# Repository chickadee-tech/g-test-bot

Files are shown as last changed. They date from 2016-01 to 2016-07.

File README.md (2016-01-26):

# Chickadee Tech Acro Polystack Mod #
This is the bottom of the test jig for Polystack **control** and **mod** boards.

## Documentation ##
See the [wiki](https://github.com/chickadee-tech/g-test-bot/wiki) for documentation.

## Polystack ##
This board is part of the Polystack platform for modular microcontrol systems. More information on the platform can be found at [polystack.org](http://polystack.org).

## Support ##
If you need support with a board you own or have development questions please email support@chickadee.tech or check [chickadee.tech/support](https://chickadee.tech/support) for other ways to get support.

## Contributing ##
Please note that this project is released with a [Contributor Code of Conduct](CODE_OF_CONDUCT.md). By participating in this project you agree to abide by its terms.

### Setup ###
Components and footprints for PCB parts are not included in this repository. Instead, checkout the [chickadee-tech/kicad-libs](https://github.com/chickadee-tech/kicad-libs) repository in the same directory that this repository is checked out in. All part definitions should be relative so that they will load correctly.

### Pull requests ###
For fixes please submit a pull request to the original repository. After the pull request is merged, check the [Chickadee Tech Active Contributor Discount (ACD)](https://chickadee.tech/active-contributor) to see if you are eligible for a discount code to use on your next purchase.

### Derivatives ###
If developing your own version of the test jig bottom board please remove all Chickadee Tech trademarks and follow the [CC-BY license](pcb/LICENSE) for the PCB and the MIT license for the code. While not required, please consider open sourcing your modifications so others can learn from your improvements. If you do email support@chickadee.tech and we may choose to add your project to the ACD.

You may also license the Polystack logo for free by emailing support@chickadee.tech. We'll ask for your gerbers to ensure the design complies with specifications laid out [here](https://github.com/chickadee-tech/polystack/wiki) and provide written permission to use the trademark after compliance has been demonstrated.

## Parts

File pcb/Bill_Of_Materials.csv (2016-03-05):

part name | symbol | size (imp) | max current | unit price | units per build | units in stock | order total | Manufacturer ID | source url | datasheet | datasheet2
C 2.2uF | C1 | 603 |  | $0.05 | 1 | 92 | $0.05 | C0603C225K9PACTU | http://www.digikey.com/product-detail/en/C0603C225K9PACTU/399-3362-1-ND/650351 |  |  |  | Total Base Cost | $51.09
C 1uF X7R | C2 | 603 |  | $0.03 | 1 | 20 | $0.03 | TMK107B7105KA-T | http://www.digikey.com/product-detail/en/TMK107B7105KA-T/587-2984-1-ND/2714177 | MF-CAP-0603-1uF | http://ds.yuden.co.jp/TYCOMPAS/ut/detail.do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 | price ranges 1.40 - 2.50
barrel jack smd | CON1 |  |  | $1.18 | 1 | 1 | $1.18 | PJ-102AH | http://www.digikey.com/product-search/en?keywords=PJ-102AH | N
red led | D1 |  |  | $0.19 | 1 | 71 | $0.19 | LTST-C190KRKT | http://www.digikey.com/product-detail/en/LTST-C190KRKT/160-1436-1-ND/386816 | MF-LED-0603-RED | http://optoelectronics.liteon.com/upload/download/DS-22-99-0151/S_110_LTST-C190KRKT.pdf
yellow led | D2 |  |  | $0.20 | 1 | 87 | $0.20 | LTST-C190KSKT | http://www.digikey.com/product-detail/en/LTST-C190KSKT/160-1437-1-ND/386818 | N | http://optoelectronics.liteon.com/upload/download/DS-22-99-0189/S_110_LTST-C190KSKT.pdf
green led | D3 |  |  | $0.19 | 1 | 83 | $0.19 | LTST-C190KGKT | http://www.digikey.com/product-detail/en/LTST-C190KGKT/160-1435-1-ND/386814 | Y | http://optoelectronics.liteon.com/upload/download/DS22-2000-074/S_110_LTST-C190KGKT.pdf
1x6 Female 5mm Tin | P1 |  |  | $1.20 | 1 | 1 | $1.20 | CES-106-01-T-S | http://www.digikey.com/product-detail/en/CES-106-01-T-S/SAM1087-06-ND/1104168 | N | http://suddendocs.samtec.com/prints/ces-dmkt.pdf
2x25 Female 5mm Tin | P2, P4 |  |  | $4.54 | 2 | 0 | $9.08 | CES-125-01-T-D | http://www.digikey.com/product-detail/en/CES-125-01-T-D/SAM1086-25-ND/1104099 | N | http://suddendocs.samtec.com/prints/ces-dmkt.pdf
1x4 Female 5mm Gold | P3 |  |  | $2.37 | 1 | 1 | $2.37 | CES-104-01-S-S | http://www.digikey.com/product-detail/en/CES-104-01-S-S/SAM1085-04-ND/1104070 | N | http://suddendocs.samtec.com/prints/ces-dmkt.pdf
side entry top 16pos 1mm | P5, P8 |  |  | $0.80 | 2 | 1 | $1.60 | SFW16R-2STE1LF | http://www.digikey.com/product-detail/en/SFW16R-2STE1LF/609-1908-1-ND/1003193 | N
20 pin receptacle (3.5mm) | P6 |  |  | $0.78 | 1 | 0 | $0.78 | DF40HC(3.5)-20DS-0.4V(51) |  | N | http://www.hirose.co.jp/cataloge_hp/ed_DF40_20140305.pdf
3.5mm pogopin | P7 |  |  | $1.41 | 1 | 0 | $1.41 | 0910-8-57-20-76-14-11-0 | http://www.digikey.com/product-detail/en/0910-8-57-20-76-14-11-0/ED1422CT-ND/5722687 | N | https://www.mill-max.com/assets/pdfs/metric/026M.pdf
80 pin receptacle (3.5mm) | PORT_OUT1 |  | 0.3A a pin | $2.42 | 1 | 1 | $2.42 | DF40HC(3.5)-80DS-0.4V(51) | http://www.digikey.com/product-detail/en/DF40HC(3.5)-80DS-0.4V(51)/H11997CT-ND/2880228 | N | http://www.hirose.co.jp/cataloge_hp/ed_DF40_20140305.pdf
n-channel mosfet | Q1 | TO-236-3, SC-59, SOT-23-3 | 220mA continuous | $0.09 | 1 | 59 | $0.09 | BSS138 | http://www.digikey.com/product-detail/en/BSS138/BSS138CT-ND/244294 | MF-DSC-SOT233-BSS138 | https://www.fairchildsemi.com/datasheets/BS/BSS138.pdf
R 1k | R1, R2, R3 | 603 |  | $0.01 | 3 | 993 | $0.03 | RC0603FR-071KL | http://www.digikey.com/product-detail/en/RC0603FR-071KL/311-1.00KHRCT-ND/729790 | MF-RES-0603-1K | http://www.yageo.com/NewPortal/yageodocoutput?fileName=/pdf/R-Chip/PYu-RC_Group_51_RoHS_L_3.pdf
R 0 | R4, R5 | 603 |  | $0.00 | 2 | 92 | $0.01 | RC0603JR-070RL | http://www.digikey.com/product-search/en?keywords=311-0.0grct-nd
dpdt | SW1 |  | 200mA | $1.35 | 1 | 0 | $1.35 | CL-SB-22B-02T | http://www.digikey.com/product-detail/en/CL-SB-22B-02T/563-1343-1-ND/3507867 | N | http://www.nidec-copal-electronics.com/e/catalog/switch/cl-sb.pdf
tactile switch top | SW2 |  |  | $0.24 | 1 | 3 | $0.24 | PTS645SK50SMTR92 LFS | http://www.digikey.com/product-search/en?keywords=ckn9087ct-nd | MF-SW-TACT-6MM
high side power switch | U1 | sot23-5 | 500mA | $0.65 | 1 | 0 | $0.65 | STMPS2151STR | http://www.digikey.com/product-detail/en/STMPS2151STR/497-6934-1-ND/1880312 | N | http://www.st.com/web/en/resource/technical/document/datasheet/CD00167470.pdf
3.3v regulator | U2 | SOT23-5 | 0.3A | $0.49 | 1 | 8 | $0.49 | TLV70233DBVR | http://www.digikey.com/product-detail/en/TLV70233DBVR/296-32415-1-ND/3505572 | MF-REG-SOT235-3.3V-300mA | http://www.ti.com/lit/ds/symlink/tlv702.pdf
4 x 1:2 | U3 | 16-VFQFN Exposed Pad |  | $0.63 | 1 | 1 | $0.63 | 74CBTLV3257BQ,115 | http://www.digikey.com/product-detail/en/nxp-semiconductors/74CBTLV3257BQ,115/568-5423-1-ND/2530901 | N | http://www.nxp.com/documents/data_sheet/74CBTLV3257.pdf
Generic Bottom Test Jig | Off board |  |  | $13.03 | 1 | 3 | $13.03 | CKD-G-TEST-BOT-V2 |  | N
STM32F3Discovery | STM32 F3 Discovery |  |  | $11.57 | 1 | 1 | $11.57 | STM32F3Discovery | http://www.digikey.com/product-search/en?keywords=stm32f3discovery | N | http://www.st.com/st-web-ui/static/active/en/resource/technical/document/user_manual/DM00063382.pdf
Nylon Hex Nut | Off board |  |  | $0.10 | 4 | 94 | $0.38 | 4688 | http://www.mouser.com/ProductDetail/Keystone-Electronics/4688/ | N | http://www.mouser.com/ds/2/215/688-744520.pdf
~1.25mm Spacer | Off Board |  |  | $0.08 | 4 | 8 | $0.34 | 908-050 |  | N
6" Premo Flex 16 pos FPC | Off board |  |  | $1.56 | 1 | 1 | $1.56 | 98267-0321 | http://www.digikey.com/product-detail/en/molex-llc/0210390317/WM10031-ND/376526
R 220 | R4, R5, R6 | 603 |  | $0.00 | 3 | 493 | $0.01 | RC0603JR-07220RL | http://www.digikey.com/product-detail/en/yageo/RC0603JR-07220RL/311-220GRCT-ND/729688 | MF-RES-0603-220 | http://www.yageo.com/NewPortal/yageodocoutput?fileName=/pdf/R-Chip/PYu-RC_Group_51_RoHS_L_3.pdf
R 10k | R7, R8 | 603 |  | $0.01 | 2 | 979 | $0.02 | RC0603FR-0710KL | http://www.digikey.com/product-detail/en/RC0603FR-0710KL/311-10.0KHRCT-ND/729827 | MF-RES-0603-10K | http://www.yageo.com/NewPortal/yageodocoutput?fileName=/pdf/R-Chip/PYu-RC_Group_51_RoHS_L_3.pdf

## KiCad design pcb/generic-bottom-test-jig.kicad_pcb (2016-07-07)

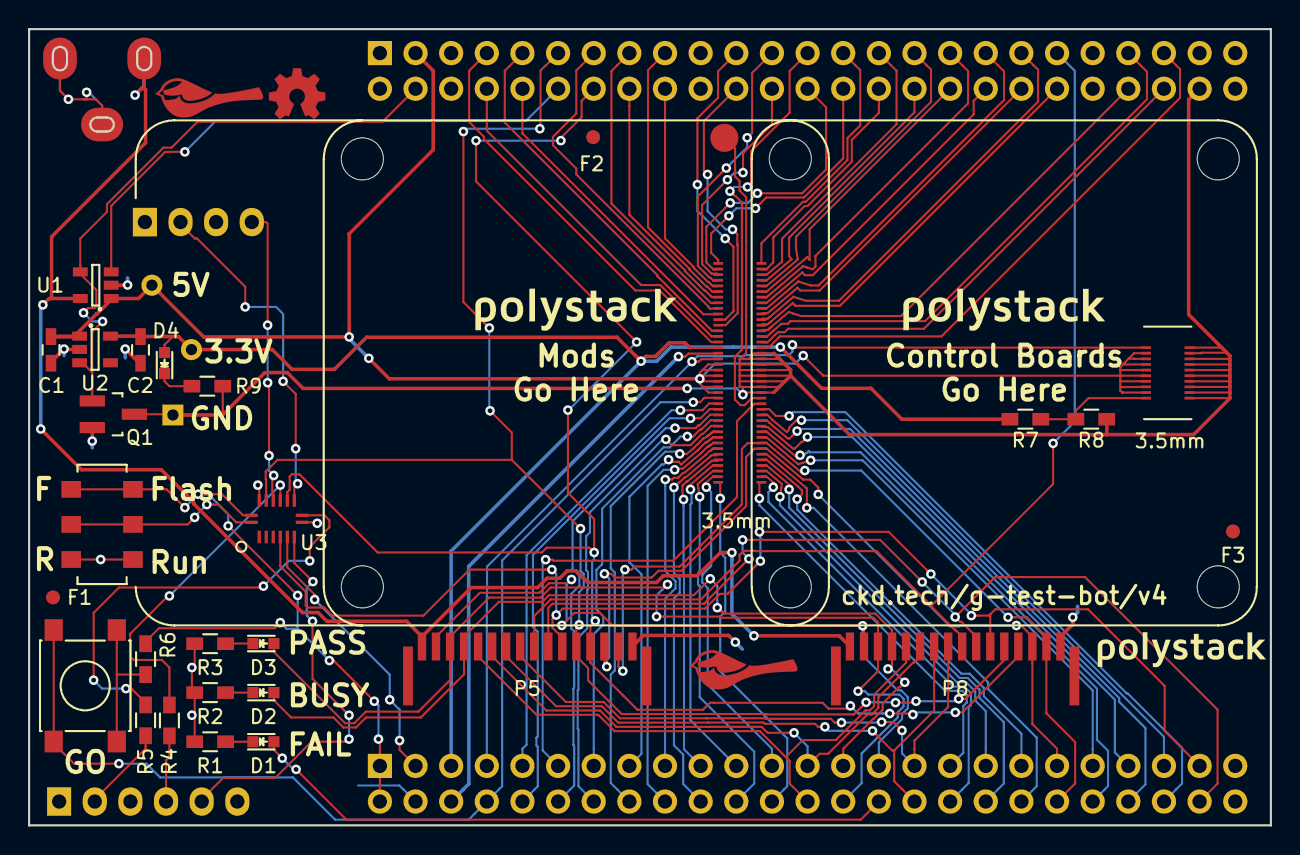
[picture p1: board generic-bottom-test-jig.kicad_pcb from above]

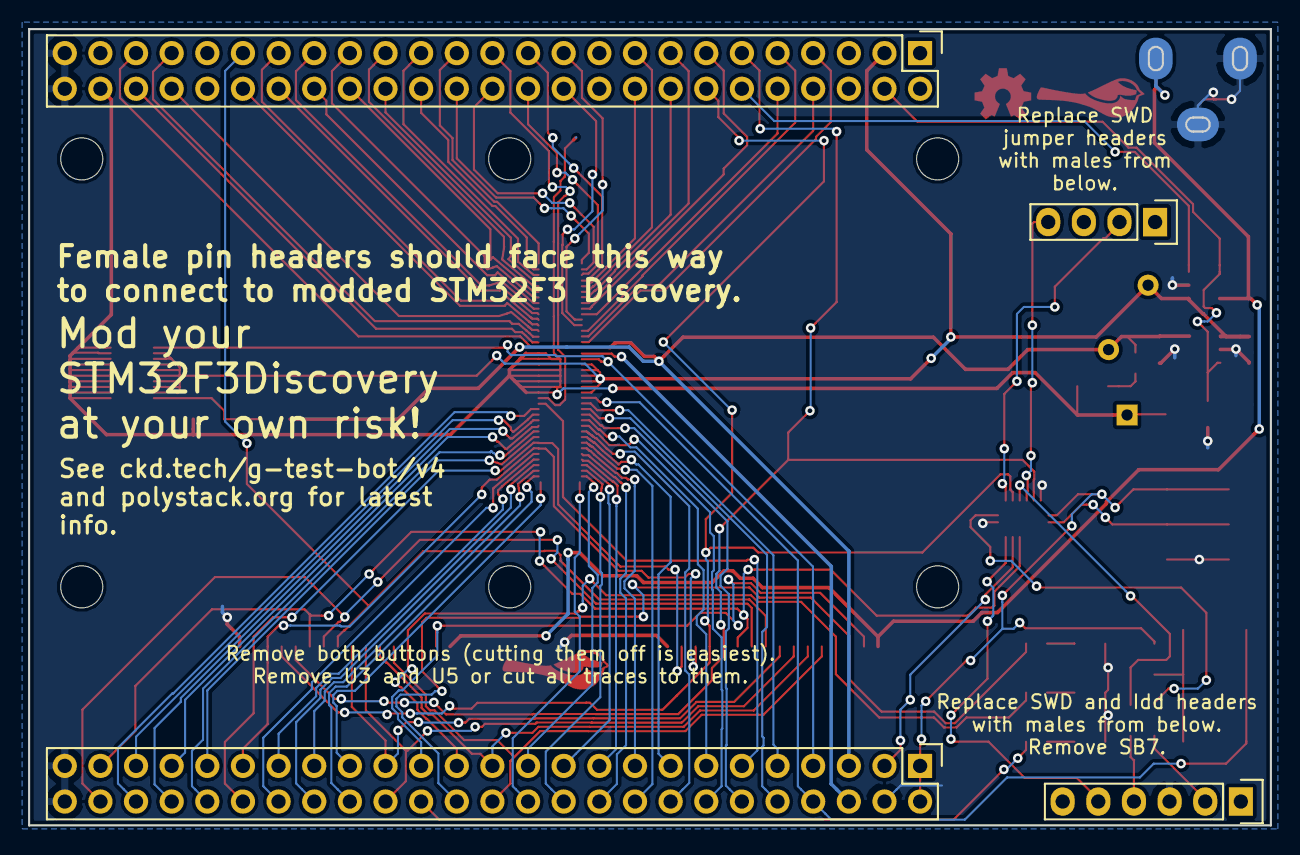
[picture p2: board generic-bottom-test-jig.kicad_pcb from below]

Board: 2 copper layers, 88.5 x 56.8 mm, 40 parts (4 on the bottom side), 101 nets.

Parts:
C1: 2.2uF; C_0603_HandSoldering
C2: 1uF; C_0603_HandSoldering
CON1: BARREL_JACK; PJ-037BH-SMT-OVAL-EDGE
D1, D4: RED; LED_0603
D2: YELLOW; LED_0603
D3: GREEN; LED_0603
F1, F2, F3: 1mm; Fiducial
P1: CONN_01X06; Pin_Header_Straight_1x06
P2, P4: CONN_02X25; Pin_Header_Straight_2x25
P3: CONN_01X04; Pin_Header_Straight_1x04
P5, P8: CONN_01X16; SFW12LF-16pin
P6: CONN_02X10; DF40-1.5mm-20pin-Receptacle
P7: CONN_01X01; 0910
P9, P10: CONN_01X01; Measurement_Point_Round-TH_Small
P11: CONN_01X01; Measurement_Point_Square-TH_Small
PORT_OUT1: CKD_SANDWICH; DF40-3-4mm-80pin-Receptacle
Q1: Q_NMOS_GSD; SOT-23_Handsoldering
R1, R2, R3, R9: 1k; R_0603_HandSoldering
R4, R5: 0; R_0603_HandSoldering
R6: 220; R_0603_HandSoldering
R7, R8: 10k; R_0603_HandSoldering
SW1: Switch_SPDT_x2; CL-SB-22B
SW2: SPST; SW_SPST_PTS645
U1: STMPS2151; SOT-23-5
U2: TLV70233DBV; SOT-23-5
U3: 74LS257; SOT763-1(DHVQFN16)
svg2mod, svg2mod#2: G***; polystack-bold-0.75
svg2mod#3: G***; polystack-bold-0.625

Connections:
+5V: CON1.1, P5.1, P8.1, U1.5
/HOST_SWCLK: P3.2, U3.10
/HOST_SWDIO: P3.4, U3.13
/HOST_nRST: P2.3, U3.6
/PA0_MEZ_RESET: P2.11, PORT_OUT1.66
/PA1: P2.10, PORT_OUT1.27
/PA2: P2.13, PORT_OUT1.29
/PA3: P2.12, PORT_OUT1.28
/PA4: P2.15, PORT_OUT1.32
/PA5_SCL: P2.16, PORT_OUT1.31
/PA6_SDO: P2.17, PORT_OUT1.34
/PA7_SDA: P2.18, PORT_OUT1.33
/PA8: P4.46, PORT_OUT1.55
/PA9: P4.43, PORT_OUT1.54
/PA10: P4.44, PORT_OUT1.53
/PA13_SWDIO: P4.39, P5.9, P8.9
/PA14_SWCLK: P4.38, PORT_OUT1.50
/PA15: P4.37, PORT_OUT1.51
/PB0: P2.21, PORT_OUT1.37
/PB1: P2.22, PORT_OUT1.38
/PB2: P2.23, PORT_OUT1.39
/PB3_SWO_MEZ_BOOT: P4.25, PORT_OUT1.65
/PB4: P4.24, PORT_OUT1.3
/PB5: P4.23, PORT_OUT1.4
/PB6_SCL: P4.22, PORT_OUT1.12
/PB7_SDA: P4.21, PORT_OUT1.11
/PB8: P4.18, PORT_OUT1.5
/PB9: P4.17, PORT_OUT1.6
/PB10: P2.33, PORT_OUT1.80
/PB11: P2.34, PORT_OUT1.79
/PB12: P2.35, PORT_OUT1.78
/PB13: P2.36, PORT_OUT1.77
/PB14: P2.37, PORT_OUT1.76
/PB15: P2.38, PORT_OUT1.75
/PC0_3V3: C2.1, D4.2, P2.5, P10.1, PORT_OUT1.16, R7.1, U2.5
/PC1_3V3_E: P2.6, PORT_OUT1.17
/PC2_BATT: P2.7, P6.19, PORT_OUT1.18
/PC3_SWITCH: P2.8, PORT_OUT1.25, SW2.1
/PC4: P2.19, PORT_OUT1.36
/PC5: P2.20, PORT_OUT1.35
/PC6_BOOT0: P2.48, P5.10, P8.10
/PC7_RESET: P2.47, P5.11, P8.11, U3.5
/PC8_GND: P4.48, P6.2, P6.4, P6.6, P6.8, P6.10, P6.12, P6.14, P6.16, P6.18, P6.20, P7.1, P11.1, PORT_OUT1.57, PORT_OUT1.58, PORT_OUT1.59, PORT_OUT1.60, PORT_OUT1.61, PORT_OUT1.62, PORT_OUT1.63, PORT_OUT1.64, Q1.3, R8.2, R9.2
/PC9: P4.45, PORT_OUT1.56
/PC10: P4.36, PORT_OUT1.48
/PC11: P4.35, PORT_OUT1.49
/PC12: P4.34, PORT_OUT1.46
/PC13: P4.9, PORT_OUT1.13
/PC14: P4.8, PORT_OUT1.14
/PC15: P4.7, PORT_OUT1.15
/PD0: P4.33, PORT_OUT1.47
/PD1: P4.32, PORT_OUT1.44
/PD2: P4.31, PORT_OUT1.45
/PD3: P4.30, PORT_OUT1.42
/PD4: P4.29, PORT_OUT1.43
/PD5: P4.28, PORT_OUT1.1
/PD6: P4.27, PORT_OUT1.41
/PD7: P4.26, PORT_OUT1.2
/PD8_TX: P2.39, P5.14, P8.14, PORT_OUT1.74
/PD9_RX: P2.40, P5.15, P8.15, PORT_OUT1.73
/PD10: P2.41, PORT_OUT1.72
/PD11: P2.42, PORT_OUT1.71
/PD12: P2.43, PORT_OUT1.70
/PD13: P2.44, PORT_OUT1.69
/PD14: P2.45, PORT_OUT1.68
/PD15: P2.46, PORT_OUT1.67
/PE0: P4.16, PORT_OUT1.7
/PE1: P4.15, PORT_OUT1.8
/PE3: P4.13, PORT_OUT1.9
/PE4_FAULT: P4.12, U1.3
/PE6: P4.10, PORT_OUT1.10
/PE7: P2.24, PORT_OUT1.40
/PE8_LD4_BLUE: P2.25, P5.6, P8.6
/PE9_LD3_RED: P2.26, P5.5, P8.5
/PE10_LD5_ORANGE: D2.2, P2.27, P5.4, P8.4
/PE11_LD7_GREEN: D3.2, P2.28, P5.3, P8.3
/PE12_LD9_BLUE: P2.29, P5.2, P8.2
/PE13_LD10_RED: D1.2, P2.30
/PE14_LD8_ORANGE: P2.31, P5.8, P8.8
/PE15_LD6_GREEN: P2.32, P5.7, P8.7
/PF2: P2.9, PORT_OUT1.26
/PF4: P2.14, PORT_OUT1.30
/PF6: P4.40, PORT_OUT1.52
/PF9_POWER_ENABLE: P4.4, Q1.1, U1.4, U2.3
/PF10_5V: C1.1, P4.3, P6.3, P6.5, P6.7, P6.9, P6.11, P6.13, P6.15, P6.17, P9.1, PORT_OUT1.19, PORT_OUT1.20, PORT_OUT1.21, PORT_OUT1.22, PORT_OUT1.23, PORT_OUT1.24, U1.1, U2.1
/SWCLK: R5.1, U3.9
/SWDIO: R4.2, U3.12
/SWD_SELECT: SW1.2, SW1.5, U3.1
/TEST_SWCLK: P4.14, P5.13, P8.13, U3.11
/TEST_SWDIO: P4.11, P5.12, P8.12, U3.14
/nRST: P1.5, U3.7
GND: C1.2, C2.2, CON1.2, CON1.3, P1.3, P2.4, P2.49, P2.50, P4.49, P4.50, P5.16, P8.16, Q1.2, R1.2, R2.2, R3.2, SW1.3, SW1.6, U1.2, U2.2, U3.8, U3.15
unnamed: D1.1, R1.1
unnamed: D2.1, R2.1
unnamed: D3.1, R3.1
unnamed: D4.1, R9.1
unnamed: P1.2, R5.2
unnamed: P1.4, R4.1
unnamed: P6.1, R7.2, R8.1
unnamed: R6.2, SW2.2
VCC: P2.1, P2.2, R6.1, SW1.1, SW1.4, U3.16

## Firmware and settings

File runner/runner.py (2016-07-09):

# MIT License
#
# Copyright (c) 2016 Chickadee Tech LLC
#
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
from __future__ import print_function

import base64
import binascii
import colorama
from colorama import Fore as fore, Style as style
import datetime
import math
import os
import os.path
import serial
import serial.tools.list_ports
import struct
import sys
import time

# Init colorama so it adapts the output for Windows.
colorama.init()

os.environ["GOOGLE_APPLICATION_CREDENTIALS"] = "Chickadee-tech-Board History-2c3e589ba27e.json"

from gcloud import datastore

import polystack_pb2
from google.protobuf import text_format
from google.protobuf.internal import encoder

import subprocess

import platform

# i2c addresses for the EEPROM
MEMORY_ADDRESS = 0b10100000
SERIAL_ADDRESS = 0b10110000

SERIAL_PAGE = 0b0000100000000000
MEMORY_PAGE = 0b0000000000000000

SHIPPING_BINARIES = {"F3FC": "builds/betaflight_batch1_CKD_F3FC_V9.bin",
               "F4FC": "builds/betaflight_batch1_CKD_F4FC_V5.bin"}

DIRTY_WHITELIST = ["a6652e2-dirty Wed Jun 29 14:05:13 CDT 2016"]

PRINT_LOG = False

PORT = {"F3FC": {"0x48000000": "PA",
            "0x48000400": "PB",
            "0x48000800": "PC",
            "0x48000c00": "PD",
            "0x48001000": "PE",
            "0x48001400": "PF"},
      "F4FC": {"0x40020000": "PA",
            "0x40020400": "PB",
            "0x40020800": "PC",
            "0x40020c00": "PD",
            "0x40021000": "PE",
            "0x40021400": "PF",
            "0x40021800": "PG",
            "0x40021c00": "PH"}}

# Constants for talking with the code on the test control board.
ECHO = 0
TEST_DATA = 1
CONTINUE = 2
TEST_INTERNAL_DATA = 3
READ_UNIQUE_ID = 4
TEST_GYRO = 5

TOP_TO_FS = {
  0: "TIM1",
  1: "TIM2",
  2: "TIM3",
  3: "TIM4",
  4: "GPIO3",
  5: "GPIO4",
  6: "GPIO5",
  7: "GPIO6",
  8: "i2c_SDA",
  9: "i2c_SCL",
  10: "HEIGHT_4",
  11: "HEIGHT_2",
  12: "HEIGHT_1",
  13: "3V3_0.3A_LL",
  14: "3V3_0.3A_E",
  15: "+BATT",
  16: "5V",
  17: "UART8_TX",
  18: "UART8_RX",
  19: "UART7_TX",
  20: "UART7_RX",
  21: "UART6_TX",
  22: "UART6_RX",
  23: "UART5_TX",
  24: "UART5_RX",
  25: "UART4_TX",
  26: "UART4_RX",
  27: "UART3_TX",
  28: "UART3_RX",
  29: "UART2_TX",
  30: "UART2_RX",
  31: "TIMG1_CH1",
  32: "TIMG1_CH2",
  33: "TIMG1_CH3",
  34: "TIMG1_CH4",
  35: "TIMG2_CH1",
  36: "TIMG2_CH2",
  37: "TIMG2_CH3",
  38: "TIMG2_CH4",
  39: "ADC1",
  40: "ADC2",
  41: "SDMMC1_D0",
  42: "SDMMC1_D1",
  43: "SDMMC1_D2",
  44: "SDMMC1_D3",
  45: "SDMMC1_CK",
  46: "SDMMC1_CMD",
  47: "GND",
  48: "CAN_HI",
  49: "CAN_LO",
  50: "SPI3_NSS",
  51: "SPI3_SCK",
  52: "SPI3_MISO",
  53: "SPI3_MOSI",
  54: "SPI2_NSS",
  55: "SPI2_SCK",
  56: "SPI2_MISO",
  57: "SPI2_MOSI",
  58: "SPI1_NSS",
  59: "SPI1_SCK",
  60: "SPI1_MISO",
  61: "SPI1_MOSI",
  1000: "GPIO2",
  1001: "GPIO1",
  1002: "BOOT0",
  1003: "RESET"
}

PIN_TO_FS = {
  "PD5": "TIM1",
  "PD7": "TIM2",
  "PB4": "TIM3",
  "PB5": "TIM4",
  "PB8": "GPIO1",
  "PB9": "GPIO2",
  "PE0": "GPIO3",
  "PE1": "GPIO4",
  "PE3": "GPIO5",
  "PE6": "GPIO6",
  "PB7": "i2c_SDA",
  "PB6": "i2c_SCL",
  "PC13": "HEIGHT_4",
  "PC14": "HEIGHT_2",
  "PC15": "HEIGHT_1",
  "PC0": "3V3_0.3A_LL",
  "PC1": "3V3_0.3A_E",
  "PC2": "+BATT",
  "PF10": "5V",
  "PC3": "UART8_TX",
  "PF2": "UART8_RX",
  "PA1": "UART7_TX",
  "PA3": "UART7_RX",
  "PA2": "UART6_TX",
  "PF4": "UART6_RX",
  "PA5": "UART5_TX",
  "PA4": "UART5_RX",
  "PA7": "UART4_TX",
  "PA6": "UART4_RX",
  "PC5": "UART3_TX",
  "PC4": "UART3_RX",
  "PB0": "UART2_TX",
  "PB1": "UART2_RX",
  "PB2": "UART1_TX",
  "PE7": "UART1_RX",

  "PD6": "TIMG1_CH1",
  "PD3": "TIMG1_CH2",
  "PD4": "TIMG1_CH3",
  "PD1": "TIMG1_CH4",
  "PD2": "TIMG2_CH1",
  "PC12": "TIMG2_CH2",
  "PD0": "TIMG2_CH3",
  "PC10": "TIMG2_CH4",
  "PC11": "ADC1",
  "PA14": "ADC2",
  "PA15": "SDMMC1_D0",
  "PF6": "SDMMC1_D1",
  "PA10": "SDMMC1_D2",
  "PA9": "SDMMC1_D3",
  "PA8": "SDMMC1_CK",
  "PC9": "SDMMC1_CMD",
  "PC8": "GND",
  "PB3": "BOOT0",
  "PA0": "RESET",
  "PD15": "CAN_HI",
  "PD14": "CAN_LO",
  "PD13": "SPI3_NSS",
  "PD12": "SPI3_SCK",
  "PD11": "SPI3_MISO",
  "PD10": "SPI3_MOSI",
  "PD9": "SPI2_NSS",
  "PD8": "SPI2_SCK",
  "PB15": "SPI2_MISO",
  "PB14": "SPI2_MOSI",
  "PB13": "SPI1_NSS",
  "PB12": "SPI1_SCK",
  "PB11": "SPI1_MISO",
  "PB10": "SPI1_MOSI"
}

TOP_IGNORE = ["i2c_SDA", "i2c_SCL", "HEIGHT_2", "HEIGHT_1", "3V3_0.3A_LL", "5V"]

BROKEN_PINS = {"ABoAJ0YzVxEgOTEy": ["UART5_TX"]}

EXPECTED_INTERNAL_HIGH = {"F3FC": ["PA12", "PC13", "PC14", "PC15"], "F4FC": ["PC13", "PC14", "PC15"]}
# TODO(tannewt): Add in 8 and 9 to the expected for the F4FC because they are i2c and should read high.
DEFAULT_TOP_STATE = {"F3FC": "8,9,12,13,16,1001,1003", "F4FC": "8,9,12,13,16,1001,1003"}

GYRO_TEST_EXPECTED_09 = [0, 3, 4, 5, 6, 7, 8, 9, 10, 11, 12, 13, 17, 21]

def fatalError(message):
  print(message)
  if platform.system() == "Windows":
    print("CTRL-C to close window.")
    while True:
      pass
  sys.exit(1)

ACTIVE_LOG = []
def logWarning(msg):
  msg = msg.replace("\n", "\nW: ")
  if PRINT_LOG:
    print("W: " + msg)
  ACTIVE_LOG.append("W: " + msg)

def logError(msg):
  msg = msg.replace("\n", "\nE: ")
  if PRINT_LOG:
    print("E: " + msg)
  ACTIVE_LOG.append("E: " + msg)

def logInfo(msg):
  msg = msg.replace("\n", "\nI: ")
  if PRINT_LOG:
    print("I: " + msg)
  ACTIVE_LOG.append("I: " + msg)

def clearLog():
  global ACTIVE_LOG
  ACTIVE_LOG = []

def getLog():
  return ACTIVE_LOG

def addresses_to_pin(board, addresses):
  if not addresses:
    return ""
  port, pin = addresses.split("_")
  if board not in PORT:
    board = "F3FC"
  return PORT[board][port] + str(int(math.log(int("0x"+pin, 0), 2)))

def top_to_fs(top):
  if int(top) in TOP_TO_FS:
    return TOP_TO_FS[int(top)]
  return top

def pin_to_fs(pin):
  if pin in PIN_TO_FS:
    return PIN_TO_FS[pin]
  return pin

print("Available COM ports:")
comports = serial.tools.list_ports.comports()
if len(comports) == 0:
  fatalError("No COM ports found! Is the jig plugged in?")

for i, port in enumerate(comports):
  print(str(i) + ":", port.device, port.description)
index = raw_input("Enter the number next to the desired COM port: ")
print()
test_device_com_device = comports[int(index)].device
ser = serial.Serial(test_device_com_device, 115200, timeout=5)
print("Connected to:", ser.name)

def runCommand(command):
  logInfo(command)
  ser.write(bytes(command) + b'\n')
  command = command.split(" ")[0]
  responses = []
  while True:
    response = ser.readline().strip("\n")
    if response == "":
      continue
    if response == command + " done":
      break
    #logInfo(response)
    responses.append(response)
  logInfo("")
  return responses
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

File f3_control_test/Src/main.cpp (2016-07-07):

/**
  ******************************************************************************
  * File Name          : main.c
  * Description        : Main program body
  ******************************************************************************
  *
  * COPYRIGHT(c) 2015 STMicroelectronics
  *
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
  ******************************************************************************
  */

// MIT License
//
// Copyright (c) 2016 Chickadee Tech LLC
//
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
/* Includes ------------------------------------------------------------------*/
#include <inttypes.h>
#include <math.h>
#include <tuple>
#include <vector>
#include <utility>

#include "stm32f3xx_hal.h"


/* USER CODE BEGIN PV */

#define U_ID_0 (*(uint32_t*)0x1FFFF7AC)
#define U_ID_1 (*(uint32_t*)0x1FFFF7B0)
#define U_ID_2 (*(uint32_t*)0x1FFFF7B4)

#define ECHO 0
#define TEST_DATA 1
#define CONTINUE 2
#define TEST_INTERNAL_DATA 3
#define READ_UNIQUE_ID 4
#define TEST_GYRO 5

#define MORE_DATA 0
#define COMPLETELY_DONE 1
#define TEST_TOP_MUX 2
#define TEST_TOP_DIRECT 3
#define NO_TEST_TOP 4

// This pin turns on the green LED.
static GPIO_TypeDef* PASS_LED_GPIOx = GPIOC;
static uint16_t PASS_LED_Pin = GPIO_PIN_13;

// This pin turns on the yellow LED.
static GPIO_TypeDef* BUSY_LED_GPIOx = GPIOC;
static uint16_t BUSY_LED_Pin = GPIO_PIN_14;

// This pin turns on the red LED.
static GPIO_TypeDef* FAIL_LED_GPIOx = GPIOC;
static uint16_t FAIL_LED_Pin = GPIO_PIN_15;

// Pins for spi to communicate with MPU.
static uint16_t MPU_NSS_Pin = GPIO_PIN_4;
static uint16_t MPU_SCK_Pin = GPIO_PIN_5;
static uint16_t MPU_MISO_Pin = GPIO_PIN_6;
static uint16_t MPU_MOSI_Pin = GPIO_PIN_7;
static GPIO_TypeDef* MPU_GPIOx = GPIOA;


// This pin is connected to the button and will hang the process until pressed.
static GPIO_TypeDef* UART_TX_GPIOx = GPIOD;
static uint16_t UART_TX_Pin = GPIO_PIN_8;
static GPIO_TypeDef* UART_RX_GPIOx = GPIOD;
static uint16_t UART_RX_Pin = GPIO_PIN_9;
static uint8_t UART_command_length = 8;

const std::vector<std::tuple<GPIO_TypeDef*, uint16_t, uint16_t>> dataPins = {
  std::make_tuple(GPIOB, GPIO_PIN_8, 0), // TIM1
  std::make_tuple(GPIOB, GPIO_PIN_9, 1), // TIM2
  std::make_tuple(GPIOB, GPIO_PIN_10, 2), // TIM3
  std::make_tuple(GPIOA, GPIO_PIN_2, 3), // TIM4
  std::make_tuple(GPIOA, GPIO_PIN_13, 1001), // GPIO1
  std::make_tuple(GPIOA, GPIO_PIN_14, 1000), // GPIO2
  std::make_tuple(GPIOE, GPIO_PIN_4, 4), // GPIO3
  std::make_tuple(GPIOE, GPIO_PIN_3, 5), // GPIO4
  std::make_tuple(GPIOE, GPIO_PIN_2, 6), // GPIO5
  std::make_tuple(GPIOB, GPIO_PIN_7, 7), // GPIO6
  //{GPIOA, GPIO_PIN_10), // i2c lines that are pulled high by default.
  //{GPIOA, GPIO_PIN_9}
  // HEIGHT_4
  // HEIGHT_2
  // HEIGHT_1
  // 13: 3V3 LL
  // 3V3 E
  // {GPIOC, GPIO_PIN_0), // +Batt
  // 16: 5V
  // UART8_TX
  // UART8_RX
  std::make_tuple(GPIOB, GPIO_PIN_10, 19), // UART7_TX
  std::make_tuple(GPIOB, GPIO_PIN_11, 20), // UART7_RX
  std::make_tuple(GPIOA, GPIO_PIN_2,  21),  // UART6_TX
  std::make_tuple(GPIOA, GPIO_PIN_3,  22),  // UART6_RX
  std::make_tuple(GPIOC, GPIO_PIN_12, 23), // UART5_TX
  std::make_tuple(GPIOD, GPIO_PIN_2,  24), // UART5_RX
  std::make_tuple(GPIOC, GPIO_PIN_10, 25), // UART4_TX
  std::make_tuple(GPIOC, GPIO_PIN_11, 26), // UART4_RX
  std::make_tuple(GPIOE, GPIO_PIN_0,  27), // UART3_TX
  std::make_tuple(GPIOE, GPIO_PIN_1,  28), // UART3_RX
  std::make_tuple(GPIOD, GPIO_PIN_5,  29), // UART2_TX
  std::make_tuple(GPIOD, GPIO_PIN_6,  30), // UART2_RX
  //{GPIOD, GPIO_PIN_8), // UART1_TX These work if we got as far as talking to this program.
  //{GPIOD, GPIO_PIN_9), // UART1_RX

  // Right side
  std::make_tuple(GPIOC, GPIO_PIN_9,  31),  // TIMG1_CH1
  std::make_tuple(GPIOC, GPIO_PIN_8,  32),  // TIMG1_CH2
  std::make_tuple(GPIOC, GPIO_PIN_7,  33),  // TIMG1_CH3
  std::make_tuple(GPIOC, GPIO_PIN_6,  34),  // TIMG1_CH4
  std::make_tuple(GPIOD, GPIO_PIN_15, 35), // TIMG2_CH1
  std::make_tuple(GPIOD, GPIO_PIN_14, 36), // TIMG2_CH2
  std::make_tuple(GPIOD, GPIO_PIN_13, 37), // TIMG2_CH3
  std::make_tuple(GPIOD, GPIO_PIN_12, 38), // TIMG2_CH4
  std::make_tuple(GPIOC, GPIO_PIN_1,  39),  // ADC1
  std::make_tuple(GPIOC, GPIO_PIN_2,  40),  // ADC2
  // Reserved pins
  // GND
  // BOOT0
  // Reset
  // Two Reserved
  // SPI3_NSS
  // SPI3_SCK
  // SPI3_MOSI
  // SPI3_MISO
  std::make_tuple(GPIOA, GPIO_PIN_15, 54), // SPI2_NSS
  std::make_tuple(GPIOB, GPIO_PIN_3,  55), // SPI2_SCK
  std::make_tuple(GPIOB, GPIO_PIN_4,  56), // SPI2_MISO
  std::make_tuple(GPIOB, GPIO_PIN_5,  57), // SPI2_MOSI
  std::make_tuple(GPIOB, GPIO_PIN_12, 58), // SPI1_NSS
  std::make_tuple(GPIOB, GPIO_PIN_13, 59), // SPI1_SCK
  std::make_tuple(GPIOB, GPIO_PIN_14, 60), // SPI1_MISO
  std::make_tuple(GPIOB, GPIO_PIN_15, 61) // SPI1_MOSI
};

// Only tested for shorts, not connectivity.
const std::vector<std::pair<GPIO_TypeDef*, uint16_t>> internalDataPins = {
  {GPIOE, GPIO_PIN_9},  // MOTOR1
  {GPIOE, GPIO_PIN_11}, // MOTOR2
  {GPIOE, GPIO_PIN_13}, // MOTOR3
  {GPIOE, GPIO_PIN_14},  // MOTOR4
  {GPIOA, GPIO_PIN_11}, // USB D-
  {GPIOA, GPIO_PIN_12}, // USB D+
  {GPIOC, GPIO_PIN_13}, // LED0
  {GPIOC, GPIO_PIN_14}, // LED1
  {GPIOC, GPIO_PIN_15} // LED2
};

/* USER CODE END PV */

void SystemClock_Config(void);
static void MX_GPIO_Init(void);

/* USER CODE BEGIN PFP */
void Input_Z(GPIO_TypeDef* GPIOx, uint16_t GPIO_Pin);
void Output_High(GPIO_TypeDef* GPIOx, uint16_t GPIO_Pin);
void Enable_SWD(void);

/* USER CODE END PFP */

/* USER CODE BEGIN 0 */
static UART_HandleTypeDef hUART;

HAL_StatusTypeDef receive(uint8_t* buffer) {
  return HAL_UART_Receive(&hUART, (unsigned char*) buffer, UART_command_length, 1000);
}

void wait(void) {
  uint8_t receiveBuffer[UART_command_length];
  while (receive(receiveBuffer) != HAL_OK) {
    HAL_GPIO_TogglePin(BUSY_LED_GPIOx, BUSY_LED_Pin);
  }
}

void send(uint8_t status, uint8_t* buffer, uint8_t buffer_length) {
  uint8_t transmitBuffer[UART_command_length + 1];
  transmitBuffer[0] = MORE_DATA;
  uint8_t total_transmitted = 0;
  while (total_transmitted < buffer_length) {
    if (buffer_length - total_transmitted <= UART_command_length) {
      transmitBuffer[0] = status;
    }
    for (int i = 0; i < UART_command_length; i++) {
      if (total_transmitted < buffer_length) {
        transmitBuffer[i+1] = buffer[total_transmitted];
      } else {
        transmitBuffer[i+1] = 0;
      }
      total_transmitted++;
    }
    if (HAL_UART_Transmit(&hUART, (unsigned char*) transmitBuffer, UART_command_length + 1, 1000) != HAL_OK) {
      Output_High(FAIL_LED_GPIOx, FAIL_LED_Pin);
      Output_High(BUSY_LED_GPIOx, BUSY_LED_Pin);
      for (int i = 0; i < 10; i++) {
        HAL_GPIO_TogglePin(FAIL_LED_GPIOx, FAIL_LED_Pin);
        HAL_GPIO_TogglePin(BUSY_LED_GPIOx, BUSY_LED_Pin);
        HAL_Delay(50);
      }
    }
    HAL_Delay(100);
  }
}

void packPinInfo(GPIO_TypeDef* GPIOx, uint16_t GPIO_Pin, uint8_t* output) {
  // GPIO address
  output[0] = ((uint32_t) GPIOx) >> 24;
  output[1] = ((uint32_t) GPIOx) >> 16;
  output[2] = ((uint32_t) GPIOx) >> 8;
  output[3] = ((uint32_t) GPIOx);
  // Pin
  output[4] = GPIO_Pin >> 8;
  output[5] = GPIO_Pin;
}

void testData(void) {
  // Set everything to input.
  for (uint i = 0; i < dataPins.size(); ++i) {
    Input_Z(std::get<0>(dataPins[i]), std::get<1>(dataPins[i]));
  }
  HAL_Delay(1);

  for (uint i = 0; i < dataPins.size(); ++i) {
    Output_High(std::get<0>(dataPins[i]), std::get<1>(dataPins[i]));
    HAL_Delay(10);

    // Check where we read high from our other pins.
    uint16_t shorted[16];
    uint8_t numShorted = 0;
    for (uint j = i + 1; j < dataPins.size(); ++j) {
      if (numShorted == 16) break;
      if (std::get<0>(dataPins[j]) == std::get<0>(dataPins[i]) &&
         std::get<1>(dataPins[j]) == std::get<1>(dataPins[i])) {
        continue;
      }
      if (HAL_GPIO_ReadPin(std::get<0>(dataPins[j]), std::get<1>(dataPins[j])) == GPIO_PIN_SET) {
        shorted[numShorted++] = j;
      }
    }

    uint32_t packetLength = 6 * (numShorted + 1) + 1;
    uint8_t pinInfo[packetLength];
    packPinInfo(std::get<0>(dataPins[i]), std::get<1>(dataPins[i]), pinInfo+1);
    uint16_t readIndex = std::get<2>(dataPins[i]);
    uint8_t status = TEST_TOP_MUX;
    if (readIndex >= 1000) {
      pinInfo[0] = (uint8_t) readIndex - 1000;
      status = TEST_TOP_DIRECT;
    } else {
      pinInfo[0] = (uint8_t) readIndex;
    }
    for (int j = 0; j < numShorted; j++) {
      packPinInfo(std::get<0>(dataPins[shorted[j]]), std::get<1>(dataPins[shorted[j]]), pinInfo + 7 + 6 * j);
    }

    bool isLastPin = i == dataPins.size() - 1;
    if (isLastPin) {
      status = COMPLETELY_DONE;
    }

    send(status, pinInfo, packetLength);

    if (!isLastPin) {
      // Wait for the test jig to read the top.
      wait();
      HAL_Delay(50);
    }

    Input_Z(std::get<0>(dataPins[i]), std::get<1>(dataPins[i]));
    HAL_Delay(10);
  }

  // Deinit all of the data pins so they return to their default state. This
  // includes the SWD pins.
  for (uint i = 0; i < dataPins.size(); ++i) {
    HAL_GPIO_DeInit(std::get<0>(dataPins[i]), std::get<1>(dataPins[i]));
  }
  Enable_SWD();
}

void testInternalData(void) {
  // Set everything to input.
  for (uint i = 0; i < internalDataPins.size(); ++i) {
    Input_Z(internalDataPins[i].first, internalDataPins[i].second);
  }
  HAL_Delay(1);

  for (uint i = 0; i < internalDataPins.size(); ++i) {
    Output_High(internalDataPins[i].first, internalDataPins[i].second);
    HAL_Delay(10);

    // Check where we read high from our other pins.
    uint16_t shorted[16];
    uint8_t numShorted = 0;
    for (uint j = i + 1; j < internalDataPins.size(); ++j) {
      if (numShorted == 16) break;
      if (HAL_GPIO_ReadPin(internalDataPins[j].first, internalDataPins[j].second) == GPIO_PIN_SET) {
        shorted[numShorted++] = j;
      }
    }

    uint32_t packetLength = 6 * (numShorted + 1);
    uint8_t pinInfo[packetLength];
    packPinInfo(internalDataPins[i].first, internalDataPins[i].second, pinInfo);
    uint8_t status = NO_TEST_TOP;
    for (int j = 0; j < numShorted; j++) {
      packPinInfo(internalDataPins[shorted[j]].first, internalDataPins[shorted[j]].second, pinInfo + 6 + 6 * j);
    }

    bool isLastPin = i == internalDataPins.size() - 1;
    if (isLastPin) {
      status = COMPLETELY_DONE;
    }

    send(status, pinInfo, packetLength);

    Input_Z(internalDataPins[i].first, internalDataPins[i].second);
    HAL_Delay(10);
  }

  // Deinit all of the data pins so they return to their default state. This
  // includes the SWD pins.
  for (uint i = 0; i < dataPins.size(); ++i) {
    HAL_GPIO_DeInit(std::get<0>(dataPins[i]), std::get<1>(dataPins[i]));
  }
  Enable_SWD();
}

void readUniqueId(void) {
  uint8_t idBuffer[3 * 4];
  idBuffer[0] = U_ID_0 >> 24;
  idBuffer[1] = U_ID_0 >> 16;
  idBuffer[2] = U_ID_0 >> 8;
  idBuffer[3] = U_ID_0;
  idBuffer[4] = U_ID_1 >> 24;
  idBuffer[5] = U_ID_1 >> 16;
  idBuffer[6] = U_ID_1 >> 8;
  idBuffer[7] = U_ID_1;
  idBuffer[8] = U_ID_2 >> 24;
  idBuffer[9] = U_ID_2 >> 16;
  idBuffer[10] = U_ID_2 >> 8;
  idBuffer[11] = U_ID_2;
  send(COMPLETELY_DONE, idBuffer, 3 * 4);
}

SPI_HandleTypeDef hspi;

void HAL_SPI_MspInit(SPI_HandleTypeDef *hspi) {
  if (hspi->Instance == SPI1) {
    __HAL_RCC_SPI1_CLK_ENABLE();

    GPIO_InitTypeDef GPIO_InitStruct;
    GPIO_InitStruct.Pin = MPU_SCK_Pin | MPU_MISO_Pin | MPU_MOSI_Pin;
    GPIO_InitStruct.Mode = GPIO_MODE_AF_PP;
    GPIO_InitStruct.Pull = GPIO_NOPULL;
    GPIO_InitStruct.Speed = GPIO_SPEED_FREQ_HIGH;
    GPIO_InitStruct.Alternate = GPIO_AF5_SPI1;
    HAL_GPIO_Init(MPU_GPIOx, &GPIO_InitStruct);

    GPIO_InitStruct.Pin = MPU_NSS_Pin;
    GPIO_InitStruct.Mode = GPIO_MODE_OUTPUT_PP;
    GPIO_InitStruct.Pull = GPIO_NOPULL;
    GPIO_InitStruct.Speed = GPIO_SPEED_FREQ_HIGH;
    GPIO_InitStruct.Alternate = GPIO_AF5_SPI1;
    HAL_GPIO_Init(MPU_GPIOx, &GPIO_InitStruct);
  }
}

void HAL_SPI_MspDeInit(SPI_HandleTypeDef *hspi) {
  if (hspi->Instance == SPI1) {
    __HAL_RCC_SPI1_CLK_DISABLE();
  }
}

#define FS_250DPS 0x00

#define MPUREG_GYRO_CONFIG 0x1B
#define MPUREG_ACCEL_CONFIG		0x1C
#define MPUREG_TRIMS			0x0D

#define MPU_READ  0x80
#define MPU_WRITE 0x00

#define MPU_CLK_SEL_PLLGYROZ	    0x03

#define BIT_H_RESET 0x80
#define BITS_GYRO_ST_X			0x80
#define BITS_GYRO_ST_Y			0x40
#define BITS_GYRO_ST_Z			0x20
#define BIT_I2C_IF_DIS              0x10
#define BIT_GYRO                    3
#define BIT_ACC                     2
#define BIT_TEMP                    1

#define MPUREG_ACC 0x3B

#define MPUREG_PRODUCT_ID       0x0C
#define MPUREG_SIGNAL_PATH_RESET    0x68
#define MPUREG_USER_CTRL        0x6A
#define MPUREG_PWR_MGMT_1 0x6B
#define MPUREG_PWR_MGMT_2       0x6C
#define MPUREG_WHO_AM_I 0x75

#define MPU_TEST_SAMPLES 100

#define MPU_WHO_AM_I_VALUE 0x68

uint8_t MPURead(uint8_t address) {
  uint8_t transmitBuffer[2] = {MPU_READ | address, 0};
  uint8_t receiverBuffer[2] = {0, 0};
  HAL_GPIO_WritePin(MPU_GPIOx, MPU_NSS_Pin, GPIO_PIN_RESET);
  HAL_StatusTypeDef status = HAL_SPI_TransmitReceive(&hspi, transmitBuffer, receiverBuffer, 2, 50);
  HAL_GPIO_WritePin(MPU_GPIOx, MPU_NSS_Pin, GPIO_PIN_SET);

  if (status != HAL_OK) {
    return 0xff;
  }
  return receiverBuffer[1];
}

uint8_t MPUWrite(uint8_t address, uint8_t value) {
  uint8_t transmitBuffer[2] = {MPU_WRITE | address, value};
  uint8_t receiverBuffer[2] = {0, 0};
  HAL_GPIO_WritePin(MPU_GPIOx, MPU_NSS_Pin, GPIO_PIN_RESET);
  // NOTE(tannewt): Don't use HAL_SPI_Transmit! It doesn't manage the receive
  // buffer and will lead to shifted receive values from subsequent
  // TransmitReceive calls.
  HAL_StatusTypeDef status = HAL_SPI_TransmitReceive(&hspi, transmitBuffer, receiverBuffer, 2, 50);
  HAL_GPIO_WritePin(MPU_GPIOx, MPU_NSS_Pin, GPIO_PIN_SET);
  if (status != HAL_OK) {
    return 0xff;
  }
  return 0x09;
}

int16_t
int16_t_from_bytes(uint8_t bytes[])
{
  union {
    uint8_t    b[2];
    int16_t    w;
  } u;

  u.b[1] = bytes[0];
  u.b[0] = bytes[1];

  return u.w;
}
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
int main(void)
{

  /* MCU Configuration----------------------------------------------------------*/

  /* Reset of all peripherals, Initializes the Flash interface and the Systick. */
  HAL_Init();

  /* Configure the system clock */
  SystemClock_Config();

  /* Initialize all configured peripherals */
  MX_GPIO_Init();

  /* USER CODE BEGIN 2 */

  HAL_Delay(10);

  // Output_High(BUSY_LED_GPIOx, BUSY_LED_Pin);
  // Output_High(FAIL_LED_GPIOx, FAIL_LED_Pin);
  // Output_High(PASS_LED_GPIOx, PASS_LED_Pin);

  // Set all data pins as pulled down inputs so they can drain any rogue charge.
  cBoardCommsOn();

  /* USER CODE END 2 */

  /* Infinite loop */
  /* USER CODE BEGIN WHILE */
  bool bad_sequence = false;
  while (!bad_sequence)
  {
    uint8_t receiveBuffer[UART_command_length];
    HAL_StatusTypeDef status = receive(receiveBuffer);
    if (status == HAL_OK) {
      HAL_Delay(50);
      switch(receiveBuffer[0]) {
        case ECHO:
          // Don't respond immediately so the test jig can do a little
          // processing before listening more.
          send(COMPLETELY_DONE, receiveBuffer, UART_command_length);
          break;
        case TEST_DATA:
          testData();
          break;
        case TEST_INTERNAL_DATA:
          //HAL_GPIO_TogglePin(PASS_LED_GPIOx, PASS_LED_Pin);
          testInternalData();
          break;
        case READ_UNIQUE_ID:
          //HAL_GPIO_TogglePin(PASS_LED_GPIOx, PASS_LED_Pin);
          readUniqueId();
          break;
        case TEST_GYRO:
          testGyro();
          break;
        case CONTINUE:
          bad_sequence = true;
          break;
        default:
          break;
      }
    } else {
      HAL_GPIO_TogglePin(FAIL_LED_GPIOx, FAIL_LED_Pin);
    }
  }
  cBoardCommsOff();

  Output_High(FAIL_LED_GPIOx, FAIL_LED_Pin);
  while (1)
  {
    HAL_Delay(100);
    HAL_GPIO_TogglePin(FAIL_LED_GPIOx, FAIL_LED_Pin);
  }
  /* USER CODE END 3 */

}

void Input_Z(GPIO_TypeDef* GPIOx, uint16_t GPIO_Pin) {
  GPIO_InitTypeDef GPIO_InitStruct;
  GPIO_InitStruct.Pin = GPIO_Pin;
  GPIO_InitStruct.Mode = GPIO_MODE_INPUT;
  GPIO_InitStruct.Pull = GPIO_PULLDOWN;
  GPIO_InitStruct.Speed = GPIO_SPEED_FREQ_HIGH;
  GPIO_InitStruct.Alternate = 0;
  HAL_GPIO_Init(GPIOx, &GPIO_InitStruct);
}

void Output_High(GPIO_TypeDef* GPIOx, uint16_t GPIO_Pin) {
  GPIO_InitTypeDef GPIO_InitStruct;
  GPIO_InitStruct.Pin = GPIO_Pin;
  GPIO_InitStruct.Mode = GPIO_MODE_OUTPUT_PP;
  GPIO_InitStruct.Pull = GPIO_NOPULL;
  GPIO_InitStruct.Speed = GPIO_SPEED_FREQ_HIGH;
  GPIO_InitStruct.Alternate = 0;
  HAL_GPIO_Init(GPIOx, &GPIO_InitStruct);
  HAL_GPIO_WritePin(GPIOx, GPIO_Pin, GPIO_PIN_SET);
}

void Enable_SWD(void) {
  GPIO_InitTypeDef GPIO_InitStruct;
  GPIO_InitStruct.Pin = GPIO_PIN_13;
  GPIO_InitStruct.Mode = GPIO_MODE_AF_PP;
  GPIO_InitStruct.Pull = GPIO_PULLUP;
  GPIO_InitStruct.Speed = GPIO_SPEED_HIGH;
  GPIO_InitStruct.Alternate = GPIO_AF0_SWJ;
  HAL_GPIO_Init(GPIOA, &GPIO_InitStruct);

  GPIO_InitStruct.Pin = GPIO_PIN_14;
  GPIO_InitStruct.Mode = GPIO_MODE_AF_PP;
  GPIO_InitStruct.Pull = GPIO_PULLDOWN;
  GPIO_InitStruct.Speed = GPIO_SPEED_HIGH;
  GPIO_InitStruct.Alternate = GPIO_AF0_SWJ;
  HAL_GPIO_Init(GPIOA, &GPIO_InitStruct);
}

/** System Clock Configuration
*/
void SystemClock_Config(void)
{

  RCC_OscInitTypeDef RCC_OscInitStruct;
  RCC_ClkInitTypeDef RCC_ClkInitStruct;
  RCC_PeriphCLKInitTypeDef PeriphClkInit;

  RCC_OscInitStruct.OscillatorType = RCC_OSCILLATORTYPE_HSE;
  RCC_OscInitStruct.HSEState = RCC_HSE_ON;
  RCC_OscInitStruct.HSEPredivValue = RCC_HSE_PREDIV_DIV1;
  RCC_OscInitStruct.PLL.PLLState = RCC_PLL_ON;
  RCC_OscInitStruct.PLL.PLLSource = RCC_PLLSOURCE_HSE;
  RCC_OscInitStruct.PLL.PLLMUL = RCC_PLL_MUL9;
  HAL_RCC_OscConfig(&RCC_OscInitStruct);

  RCC_ClkInitStruct.ClockType = RCC_CLOCKTYPE_SYSCLK|RCC_CLOCKTYPE_PCLK1;
  RCC_ClkInitStruct.SYSCLKSource = RCC_SYSCLKSOURCE_PLLCLK;
  RCC_ClkInitStruct.AHBCLKDivider = RCC_SYSCLK_DIV1;
  RCC_ClkInitStruct.APB1CLKDivider = RCC_HCLK_DIV2;
  RCC_ClkInitStruct.APB2CLKDivider = RCC_HCLK_DIV1;
  HAL_RCC_ClockConfig(&RCC_ClkInitStruct, FLASH_LATENCY_2);

  PeriphClkInit.PeriphClockSelection = RCC_PERIPHCLK_USART3;
  PeriphClkInit.Usart3ClockSelection = RCC_USART3CLKSOURCE_PCLK1;
  HAL_RCCEx_PeriphCLKConfig(&PeriphClkInit);

  HAL_SYSTICK_Config(HAL_RCC_GetHCLKFreq()/1000);

  HAL_SYSTICK_CLKSourceConfig(SYSTICK_CLKSOURCE_HCLK);

  /* SysTick_IRQn interrupt configuration */
  HAL_NVIC_SetPriority(SysTick_IRQn, 0, 0);
}

/** Configure pins as
        * Analog
        * Input
        * Output
        * EVENT_OUT
        * EXTI
*/
void MX_GPIO_Init(void)
{

  /* GPIO Ports Clock Enable */
  __GPIOA_CLK_ENABLE();
  __GPIOB_CLK_ENABLE();
  __GPIOC_CLK_ENABLE();
  __GPIOD_CLK_ENABLE();
  __GPIOE_CLK_ENABLE();
  __GPIOF_CLK_ENABLE();

}

#ifdef USE_FULL_ASSERT

/**
   * @brief Reports the name of the source file and the source line number
   * where the assert_param error has occurred.
   * @param file: pointer to the source file name
   * @param line: assert_param error line source number
   * @retval None
   */
void assert_failed(uint8_t* file, uint32_t line)
{
  /* USER CODE BEGIN 6 */
  /* User can add his own implementation to report the file name and line number,
    ex: printf("Wrong parameters value: file %s on line %d\r\n", file, line) */
  /* USER CODE END 6 */

}

#endif

/**
  * @}
  */

/**
  * @}
*/

/************************ (C) COPYRIGHT STMicroelectronics *****END OF FILE****/

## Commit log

2016-01-26 Beginnings of the bottom test jig schematic.
    [Bill_Of_Materials.csv, ExpansionPort.sch, generic-bottom-test-jig.kicad_pcb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]
2016-01-30 Gerbers for v1 of the test jig.
    [generic-bottom-test-jig-B.Cu.gbl, generic-bottom-test-jig-B.Mask.gbs, generic-bottom-test-jig-B.SilkS.gbo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]
2016-03-05 Initial versions of embedded test code and python code to run it.
    The model is for the embedded code to be agnostic to what its testing and simply provide commands and output to the python script that controls it. Its the Python's job to make higher level decisions such as pass/fail and whether to power it or not.
    [main.cpp, runner.py]
2016-03-05 Generic Test Jig Bottom v2 with many changes.
    * Stops sharing power enable funcitonality with addressing.
    * Fixes power connector footprint.
    * Uses a switch to fully change SWD target.
    * Stops using PF0 and PF1 which are connected to the shared oscillator which prevent stable height pins.
    * Moves the barrel connector to allow the debug board to fit.
    * Adds a voltage divider to the current pin on the power connector.
    * Adds fiducials.
    * Adds OSHW logo.
    [Bill_Of_Materials.csv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]
2016-03-21 Get i2c memory read working.
2016-04-07 Updates to the bottom test jig and addiitonal functionality in runner.
    [generic-bottom-test-jig.kicad_pcb, generic-bottom-test-jig.sch]
2016-04-13 Rebrand everything to Polystack and increment versions.
    [generic-bottom-test-jig.kicad_pcb, generic-bottom-test-jig.sch]
2016-04-16 Final gerbers for test manufacturing run.
    [generic-bottom-test-jig-B.Cu.gbl, generic-bottom-test-jig-B.Mask.gbs, generic-bottom-test-jig-B.Paste.gbp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]
2016-06-07 Test waiting on the Go button and UART communication to a control board.
2016-06-07 Remove polystack silkscreen tests and add polystack.org URL.
    [generic-bottom-test-jig.kicad_pcb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]
2016-06-17 Many fixes and features to the bottom test jig code.
    [main.cpp, runner.py]
2016-06-19 Add support for testing F3 control boards.
    Tests include:
    * Testing connectivity from the MCU under test to the Polystack connector.
    * Testing for shorts between internal pins such as the motor outputs.
    * Testing gyro communication and running its self-test.
    The test also logs the unique ID of the MCU and the product ID of the gyro for future reference.
    [main.cpp, runner.py]
2016-06-19 Generic F4 binary for running on board under test. Nothing actually implemented.
2016-06-19 Working F4 test code. Also keep track of version of test jig code running.
2016-06-25 Fixes for running on Windows. Also support checking USB connection after the test jig passes.
    [runner.py]
2016-06-25 Stop pulling the RESET pin down after Input_Z. It makes the Windows ST Link unhappy because its really undefined behavior that it works otherwise.
2016-07-06 Runner fixes that fix receiver breakout, USB plug triggering, test device append, and windows ST-LINK location.
    [runner.py]
2016-07-07 Add license information to many files. PCB design files are CC-BY and code is MIT license.
    [generic-bottom-test-jig.kicad_pcb, generic-bottom-test-jig.sch]
2016-07-07 Convert to relative component and footprint paths.
    [ExpansionPort.sch, generic-bottom-test-jig.sch]
2016-07-09 Remove print statement

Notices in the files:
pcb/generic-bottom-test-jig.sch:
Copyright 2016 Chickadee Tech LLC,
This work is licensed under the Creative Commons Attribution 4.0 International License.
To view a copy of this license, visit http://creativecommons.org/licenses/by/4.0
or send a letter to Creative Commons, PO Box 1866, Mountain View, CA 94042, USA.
